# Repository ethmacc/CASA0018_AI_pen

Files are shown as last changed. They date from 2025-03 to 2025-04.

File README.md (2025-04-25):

# CASA0018_SmartScribble
1. [Introduction](#Introduction)
2. [Materials](#Materials)
3. [Quickstart](#Quickstart)
4. [Neural Network Training](#Neural-network-training)
5. [Future work](#Limitations-and-future-work)
6. [External Links](#External-links)

## Introduction
This repository contains the code to create a simple AI-powered pen attachment. The pen attachment is able to recognize the gestures of writing handwritten numerals from 0-7, with the help of a tiny Convolutional Neural Network model, optimized to run on the Arduino Nano BLE 33 Sense.



## Materials
You will need the following components to build this project:
- Arduino Nano BLE 33 Sense
- Adafruit Neopixel 8-strip
- Protoboard or stripboard
- Wire
- Male and female pin headers
- A 3D printer and filament
- An ink pen

## Quickstart
### Software Setup
First, clone the repository using ```git clone https://github.com/ethmacc/CASA0018_SmartScribble_AI_pen_prototype```

If you want to run the project as-is, without any modifications, simply use the Arduino IDE's import zip library function to import the model and support code:



The zip library to use should be ```ei-stylus_v2-arduino-1.0.6.zip``` found in the ```builds``` folder. This contains the int8 quantized version of the best performing model found from my training runs.

Once that is done, flash the main ```stylus_v2.ino``` Arduino script onto your Nano 33 BLE Sense. This can be found in the ```stylus_v2``` folder. 

### Circuit
Using the protoboard, the wire and the pin headers, construct a small shield module to fit under the Nano. The protoboard should be no larger than the 2d footprint of the Nano in order to fit in the enclosure. The suggested arrangement of the components on the protoboard is shown below:



The circuit diagram for the protoboard is also shown below, using fritzing:



### Enclosure
3D models and print files are available in the ```enclosure``` folder. These should include everything needed to print and construct the enclosure attachment, which can then be fitted on to the end of your ink pen.



The protoboard shield and Nano should fit in snugly into the enclosure a shown:



### Usage
1. The device does not call the model to start running inference on your handwriting until you have moved it. This is due to a conditional in the code, which does not start the inference cycle if no movement is detected in the onboard inertial measurement unit (IMU)



3. Once the inference cycle has started, use the indicators displayed on the LED strip at the end of the pen to time your writing. Orange lights filling up from the bottom of the LED strip to the top indicate the model is loading and you must get ready. Red indicates that you should start writing, you have 2 seconds to write a single numeral.





4. Once inference is completed, the result will be displayed on the LED strip. A single blue light indicates that the thinks the numeral you have written is a 0, while green lights indicate that the number was recognized as more than 0. The number of green lights displays corresponds to the numeral that was recognized.



## Neural Network Training
If you want to make changes to the neural network and/or conduct your own training, please head over to the Edge Impulse project page in the external links section below. Once there, you should be able to create an account and clone the project to begin your own training. The Edge Impulse dashboard is simple and easy to use, but some further reading to edge AI and deep learning is recommended if you do not already posses the prerequisite background knowledge:



As mentioned, the model architecture is that of a Convolutional Neural Network (CNN), consisting of 3 convolution layers and 2 dense layers, with reshape, flatten and dropout layers in between:



You can find the record of the experiments run to determined the best hyperparameters and model architecture in the EON Tuner section of the Edge Impulse project page.

## Limitations and future work
The model was trained using a free account on Edge Impulse and therefore compute time was limited. You may find that your mileage may vary if you already have or decide to purchase a subscription from Edge Impulse. At present, the model is limited to classifying only the 8 classes of the numerals 0-7. It has also been trained solely on one person's handwriting data, and therefore may not be as accurate as it could be. In particular, the numerals 0 & 6 and 1 & 4 are easily confused, likely due to the similar pen strokes required to draw these characters.

Additionally, in terms of hardware, it is probably worth investigating if the electronics can be miniaturised by using a custom PCB. The prototype device also currently runs off a 5V powerbank, and it would be much better if the power supply could be integrated into the pen itself to improve ergonomics and appearance.

## External Links
Edge Impulse project: https://studio.edgeimpulse.com/studio/661138

Edge Impulse help and documentation: https://docs.edgeimpulse.com/docs

Suggested further reading:
- AI at the Edge by Situnayake and Plunkett
- TinyML by Situnayake and Warden
- Deep Learning by Courville, Goodfellow and Yoshua Bengio

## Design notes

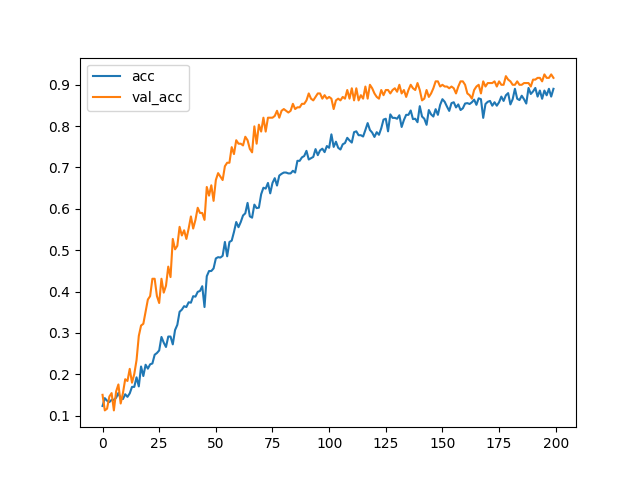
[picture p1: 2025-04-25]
media/3conv_acc.png

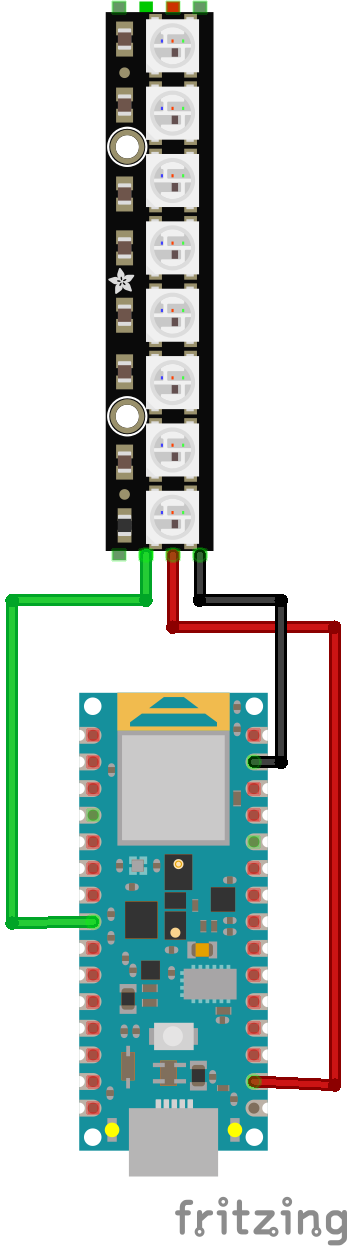
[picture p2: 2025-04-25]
media/fritzing_diagram.png

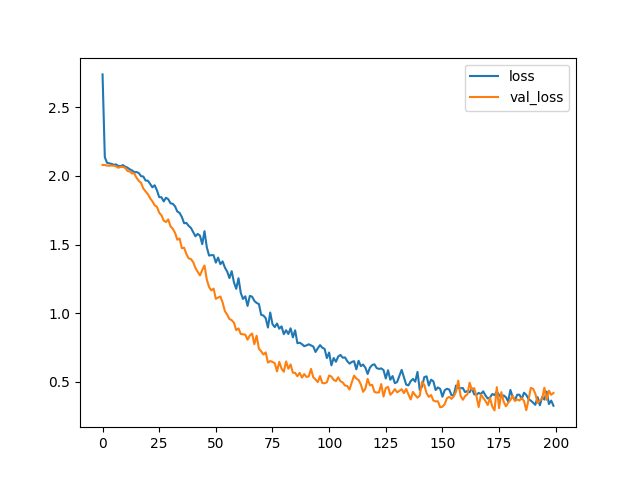
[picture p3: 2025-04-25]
media/3conv.png

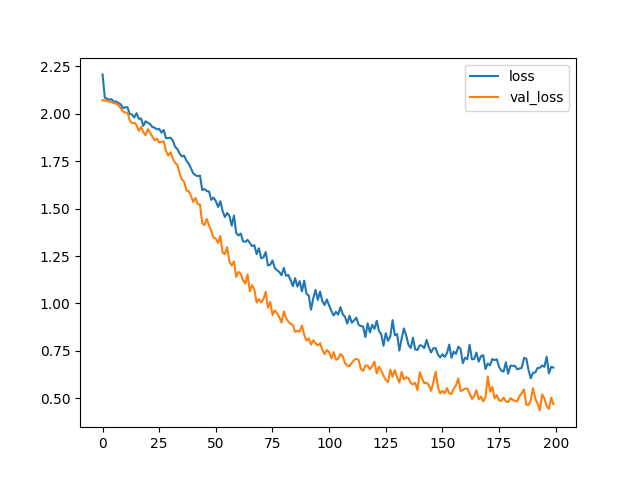
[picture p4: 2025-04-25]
media/4conv.png

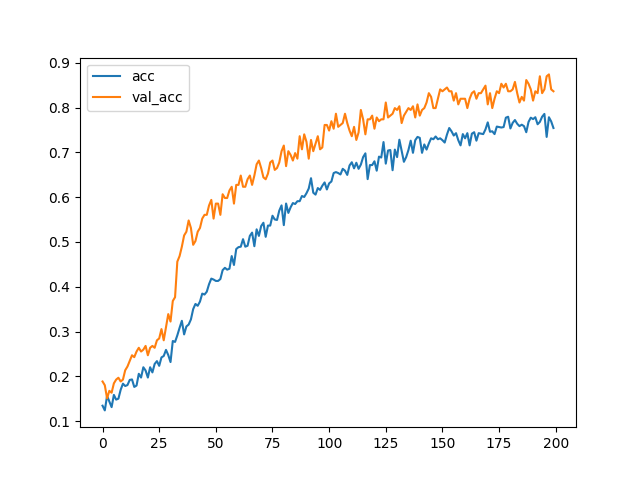
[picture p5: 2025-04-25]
media/4conv_acc.png

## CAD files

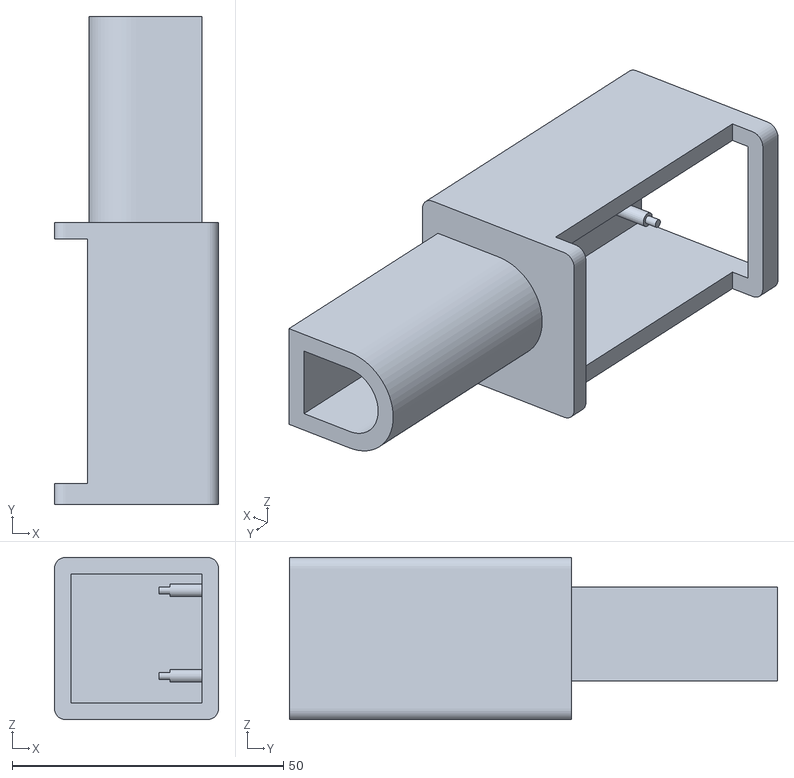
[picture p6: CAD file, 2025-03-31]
enclosure/stylus_main.stl
30.2 x 90.0 x 29.9

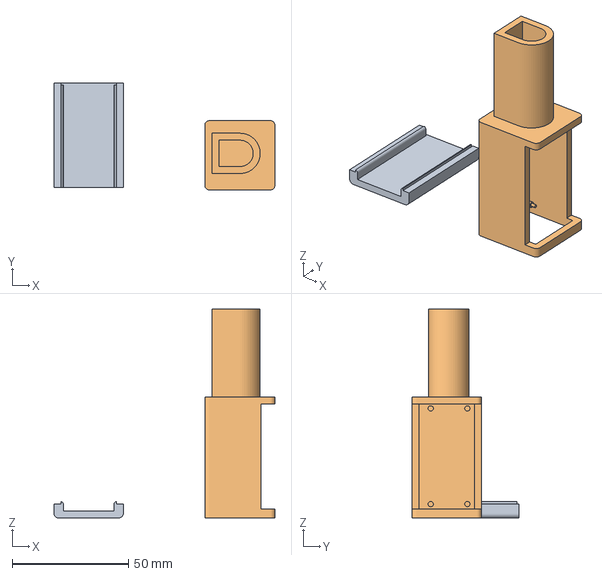
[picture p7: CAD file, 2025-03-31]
enclosure/stylus_cover.3mf
95.2 x 46.0 x 90.0 mm
stylus_cover.stl
stylus_main.stl

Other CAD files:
enclosure/stylus_cover.stl

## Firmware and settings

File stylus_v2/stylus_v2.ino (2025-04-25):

/* Edge Impulse ingestion SDK
 * Copyright (c) 2022 EdgeImpulse Inc.
 *
 * Licensed under the Apache License, Version 2.0 (the "License");
 * you may not use this file except in compliance with the License.
 * You may obtain a copy of the License at
 * http://www.apache.org/licenses/LICENSE-2.0
 *
 * Unless requiorange by applicable law or agreed to in writing, software
 * distributed under the License is distributed on an "AS IS" BASIS,
 * WITHOUT WARRANTIES OR CONDITIONS OF ANY KIND, either express or implied.
 * See the License for the specific language governing permissions and
 * limitations under the License.
 *
 */

/* Includes ---------------------------------------------------------------- */
#include <Stylus_v2_inferencing.h>
#include <Arduino_LSM9DS1.h> //Click here to get the library: https://www.arduino.cc/reference/en/libraries/arduino_lsm9ds1/
#include <Adafruit_NeoPixel.h>

#define NUMPIXELS 8
#define LEDPin D5
Adafruit_NeoPixel pixels(NUMPIXELS, LEDPin);
uint32_t green = pixels.Color(0, 20, 0);
uint32_t orange = pixels.Color(20, 10, 0);
uint32_t blue = pixels.Color(0, 0, 20);
uint32_t red = pixels.Color(20, 0, 0);

enum sensor_status {
    NOT_USED = -1,
    NOT_INIT,
    INIT,
    SAMPLED
};

/** Struct to link sensor axis name to sensor value function */
typedef struct{
    const char *name;
    float *value;
    uint8_t (*poll_sensor)(void);
    bool (*init_sensor)(void);    
    sensor_status status;
} eiSensors;

/* Constant defines -------------------------------------------------------- */
#define CONVERT_G_TO_MS2    9.80665f

/**
 * When data is collected by the Edge Impulse Arduino Nano 33 BLE Sense
 * firmware, it is limited to a 2G range. If the model was created with a
 * different sample range, modify this constant to match the input values.
 * See https://github.com/edgeimpulse/firmware-arduino-nano-33-ble-sense/blob/master/src/sensors/ei_lsm9ds1.cpp
 * for more information.
 */
#define MAX_ACCEPTED_RANGE  2.0f

/** Number sensor axes used */
#define N_SENSORS     18

/* Forward declarations ------------------------------------------------------- */
float ei_get_sign(float number);

bool init_IMU(void);

uint8_t poll_acc(void);
uint8_t poll_gyr(void);

/* Private variables ------------------------------------------------------- */
static const bool debug_nn = false; // Set this to true to see e.g. features generated from the raw signal

static float data[N_SENSORS];
static bool ei_connect_fusion_list(const char *input_list);

static int8_t fusion_sensors[N_SENSORS];
static int fusion_ix = 0;
static bool one_more;

/** Used sensors value function connected to label name */
eiSensors sensors[] =
{
    "accX", &data[0], &poll_acc, &init_IMU, NOT_USED,
    "accY", &data[1], &poll_acc, &init_IMU, NOT_USED,
    "accZ", &data[2], &poll_acc, &init_IMU, NOT_USED,
    "gyrX", &data[3], &poll_gyr, &init_IMU, NOT_USED,
    "gyrY", &data[4], &poll_gyr, &init_IMU, NOT_USED,
    "gyrZ", &data[5], &poll_gyr, &init_IMU, NOT_USED,
};

float currentAccX = data[0];

/**
* @brief      Arduino setup function
*/
void setup()
{
    /* Init serial */
    Serial.begin(115200);
    // Start neopixel
    pixels.begin();
    // comment out the below line to cancel the wait for USB connection (needed for native USB)
    //while (!Serial);
    Serial.println("Edge Impulse Sensor Fusion Inference\r\n");

    /* Connect used sensors */
    if(ei_connect_fusion_list(EI_CLASSIFIER_FUSION_AXES_STRING) == false) {
        ei_printf("ERR: Errors in sensor list detected\r\n");
        return;
    }

    /* Init & start sensors */

    for(int i = 0; i < fusion_ix; i++) {
        if (sensors[fusion_sensors[i]].status == NOT_INIT) {
            sensors[fusion_sensors[i]].status = (sensor_status)sensors[fusion_sensors[i]].init_sensor();
            if (!sensors[fusion_sensors[i]].status) {
              ei_printf("%s axis sensor initialization failed.\r\n", sensors[fusion_sensors[i]].name);             
            }
            else {
              ei_printf("%s axis sensor initialization successful.\r\n", sensors[fusion_sensors[i]].name);
            }
        }
    }
}

/**
* @brief      Get data and run inferencing
*/
void loop()
{   
    for(int i = 0; i < fusion_ix; i++) {
        sensors[fusion_sensors[i]].poll_sensor();
    }
    if (( fabs(currentAccX - data[0]) > 0.1 ) || (one_more == true)) {
        Serial.println("X moved");
        if (one_more != true) {
            one_more = true;
        }
        else {
            one_more = false;
        }

    ei_printf("\nStarting inferencing in 2 seconds...\r\n");

    for (int i = 1; i < 9; i += 1) {
        pixels.clear();
        pixels.fill(orange, 0, i);
        pixels.show();
        delay(250);
    }
    pixels.clear();
    pixels.fill(red, 0, 8);
    pixels.show();

    if (EI_CLASSIFIER_RAW_SAMPLES_PER_FRAME != fusion_ix) {
        ei_printf("ERR: Sensors don't match the sensors requiorange in the model\r\n"
        "Following sensors are requiorange: %s\r\n", EI_CLASSIFIER_FUSION_AXES_STRING);
        return;
    }

    ei_printf("Sampling...\r\n");

    // Allocate a buffer here for the values we'll read from the sensor
    float buffer[EI_CLASSIFIER_DSP_INPUT_FRAME_SIZE] = { 0 };

    for (size_t ix = 0; ix < EI_CLASSIFIER_DSP_INPUT_FRAME_SIZE; ix += EI_CLASSIFIER_RAW_SAMPLES_PER_FRAME) {
        // Determine the next tick (and then sleep later)
        int64_t next_tick = (int64_t)micros() + ((int64_t)EI_CLASSIFIER_INTERVAL_MS * 1000);

        for(int i = 0; i < fusion_ix; i++) {
            if (sensors[fusion_sensors[i]].status == INIT) {
                sensors[fusion_sensors[i]].poll_sensor();
                sensors[fusion_sensors[i]].status = SAMPLED;
            }
            if (sensors[fusion_sensors[i]].status == SAMPLED) {
                buffer[ix + i] = *sensors[fusion_sensors[i]].value;
                sensors[fusion_sensors[i]].status = INIT;
            }
        }

        int64_t wait_time = next_tick - (int64_t)micros();

        if(wait_time > 0) {
            delayMicroseconds(wait_time);
        }
    }

    // Turn the raw buffer in a signal which we can the classify
    signal_t signal;
    int err = numpy::signal_from_buffer(buffer, EI_CLASSIFIER_DSP_INPUT_FRAME_SIZE, &signal);
    if (err != 0) {
        ei_printf("ERR:(%d)\r\n", err);
        return;
    }

    // Run the classifier
    ei_impulse_result_t result = { 0 };

    err = run_classifier(&signal, &result, debug_nn);
    if (err != EI_IMPULSE_OK) {
        ei_printf("ERR:(%d)\r\n", err);
        return;
    }

    // print the porangeictions
    ei_printf("Porangeictions (DSP: %d ms., Classification: %d ms., Anomaly: %d ms.):\r\n",
        result.timing.dsp, result.timing.classification, result.timing.anomaly);
    const char* key = result.classification[0].label;
    float max = result.classification[0].value;
    for (size_t ix = 0; ix < EI_CLASSIFIER_LABEL_COUNT; ix++) {
        if (result.classification[ix].value > max) {
            max = result.classification[ix].value;
            key = result.classification[ix].label;
        }
        ei_printf("%s: %.5f\r\n", result.classification[ix].label, result.classification[ix].value);
    }
    ei_printf("MAX: %s\r\n", key);
    int num_leds = atoi(key);
    pixels.clear();
    if (num_leds > 0){
        pixels.fill(green, 0, num_leds);
    }
    else {
        pixels.fill(blue, 0, 1);
    }
    pixels.show();
    delay(2000);
#if EI_CLASSIFIER_HAS_ANOMALY == 1
    ei_printf("    anomaly score: %.3f\r\n", result.anomaly);
#endif
}
else{
    pixels.clear();
    pixels.show();
}
currentAccX = data[0];
}

#if !defined(EI_CLASSIFIER_SENSOR) || (EI_CLASSIFIER_SENSOR != EI_CLASSIFIER_SENSOR_FUSION && EI_CLASSIFIER_SENSOR != EI_CLASSIFIER_SENSOR_ACCELEROMETER)
#error "Invalid model for current sensor"
#endif


/**
 * @brief Go through sensor list to find matching axis name
 *
 * @param axis_name
 * @return int8_t index in sensor list, -1 if axis name is not found
 */
static int8_t ei_find_axis(char *axis_name)
{
    int ix;
    for(ix = 0; ix < N_SENSORS; ix++) {
        if(strstr(axis_name, sensors[ix].name)) {
            return ix;
        }
    }
    return -1;
}

/**
 * @brief Check if requested input list is valid sensor fusion, create sensor buffer
 *
 * @param[in]  input_list      Axes list to sample (ie. "accX + gyrY + magZ")
 * @retval  false if invalid sensor_list
 */
static bool ei_connect_fusion_list(const char *input_list)
{
    char *buff;
    bool is_fusion = false;

    /* Copy const string in heap mem */
    char *input_string = (char *)ei_malloc(strlen(input_list) + 1);
    if (input_string == NULL) {
        return false;
    }
    memset(input_string, 0, strlen(input_list) + 1);
    strncpy(input_string, input_list, strlen(input_list));

    /* Clear fusion sensor list */
    memset(fusion_sensors, 0, N_SENSORS);
    fusion_ix = 0;

    buff = strtok(input_string, "+");

    while (buff != NULL) { /* Run through buffer */
        int8_t found_axis = 0;

        is_fusion = false;
        found_axis = ei_find_axis(buff);

        if(found_axis >= 0) {
            if(fusion_ix < N_SENSORS) {
                fusion_sensors[fusion_ix++] = found_axis;
                sensors[found_axis].status = NOT_INIT;
            }
            is_fusion = true;
        }

        buff = strtok(NULL, "+ ");
    }

    ei_free(input_string);

    return is_fusion;
}

/**
 * @brief Return the sign of the number
 * 
 * @param number 
 * @return int 1 if positive (or 0) -1 if negative
 */
float ei_get_sign(float number) {
    return (number >= 0.0) ? 1.0 : -1.0;
}

bool init_IMU(void) {
  static bool init_status = false;
  if (!init_status) {
    init_status = IMU.begin();
  }
  return init_status;
}

uint8_t poll_acc(void) {
  
    if (IMU.accelerationAvailable()) {

    IMU.readAcceleration(data[0], data[1], data[2]);

    for (int i = 0; i < 3; i++) {
        if (fabs(data[i]) > MAX_ACCEPTED_RANGE) {
            data[i] = ei_get_sign(data[i]) * MAX_ACCEPTED_RANGE;
        }
    }

    data[0] *= CONVERT_G_TO_MS2;
    data[1] *= CONVERT_G_TO_MS2;
    data[2] *= CONVERT_G_TO_MS2;
    }

    return 0;
}

uint8_t poll_gyr(void) {
  
    if (IMU.gyroscopeAvailable()) {
        IMU.readGyroscope(data[3], data[4], data[5]);
    }
    return 0;
}

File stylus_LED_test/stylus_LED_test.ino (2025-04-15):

#include <Adafruit_NeoPixel.h>

#define NUMPIXELS 8
#define LEDPin D5
Adafruit_NeoPixel pixels(NUMPIXELS, LEDPin);
uint32_t yellow = pixels.Color(20, 20, 0);

void setup() {
  // put your setup code here, to run once:
  Serial.begin(9600);
  pixels.begin();
  pixels.clear();
  Serial.println("Turning neopixel on");
  //pixels.fill(yellow, 0, 2);
  pixels.show();
}

void loop() {
  // put your main code here, to run repeatedly:
  
  
}

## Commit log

2025-03-31 Add report draft and enclosure print files
    [stylus_cover.3mf, stylus_cover.stl, stylus_main.stl]
2025-04-16 Feat: stylus_v2 doesn't infer when no movement detected in acc
    [stylus_v2.ino]
2025-04-25 Add loss plotter and fritzing diagram
    [shield_circuit_diagram.fzz]
